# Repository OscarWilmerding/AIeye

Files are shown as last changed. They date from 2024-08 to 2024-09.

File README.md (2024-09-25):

# AIeye

If you are interested in buying a kit for this fill out this form, if there are enough people I will make and sell kits:
https://forms.gle/SYHFhyDxsT9Xxbqz5
Main repository for the AIeye camera project.

## Supplies

### Parts List
| Name | Quantity | Total Price | Link | Notes |
|---|---|---|---|---|
| Raspberry Pi Zero 2W | 1 | $26 | [Amazon](https://amzn.to/3Aza8KZ) | |
| Display | 1 | $18 | [Amazon](https://amzn.to/3WQWfPW) | |
| Camera | 1 | $9.50 | [Amazon](https://amzn.to/4cCxRY8) | |
| Camera Ribbon Cable | 1 | $9 | [Amazon](https://amzn.to/3AAfSnO) | You need this because the Pi Zero has a different ribbon cable than the regular Pi |
| Custom PCB | 1 | $9 | Recommend [PCBWay](https://www.pcbway.com/) or [JLCPCB](https://jlcpcb.com/) | You will need to upload the PCB zip file to the respective website |
| PCB Part - Button Power Switch | 1 | $1.85 | [Digi-Key](https://www.digikey.com/en/products/detail/cw-industries/GPTS203211B/3190590) | |
| PCB Part - Rotary Encoder | 1 | $2.60 | [Digi-Key](https://www.digikey.com/en/products/detail/cui-devices/RIC11-22S16D5M-TH/21705934) | |
| PCB Part - Alternate Encoder | * | * | [Digi-Key](https://www.digikey.com/en/products/detail/cui-devices/RIC11-22S15D7-TH/21705936) | Footprint should be the same for the PCB, but you may need to modify the 3D file for the knob so it fits on the shaft |
| PCB Part - Alternate Encoder | * | * | [Digi-Key](https://www.digikey.com/en/products/detail/cui-devices/RIC11-22S13D5S-TH/21705929) | Footprint should be the same for the PCB, but you may need to modify the 3D file for the knob so it fits on the shaft |
| PCB Part - Voltage Converter | 1 | $3.95 | [Digi-Key](https://www.digikey.com/en/products/detail/adafruit-industries-llc/4654/12697636) | |
| PCB Part - Momentary Button | 2 | $0.10 | [Digi-Key](https://www.digikey.com/en/products/detail/c-k/PTS636-SK43-LFS/10071716) | |
| PCB Part - Female Battery Port | 1 | $0.12 | [Digi-Key](https://www.digikey.com/en/products/detail/jst-sales-america-inc/S2B-PH-K-S/926626) | |
| Battery | 1 | $10.95 | [Digi-Key](https://www.digikey.com/en/products/detail/sparkfun-electronics/PRT-18286/14302550) | |
| Battery Charger | 1 | $10.96 | [Amazon](https://amzn.to/3yW2CcH) | |

**Total:** ~$102.03  
*Probably will cost 10-20% more with shipping included.*

---

### Other Needed Supplies

| Name | Quantity | Link | Notes |
|---|---|---|---|
| 3D Printed Parts | | | |
| M3 Screws | 2 short (5-10mm), 2 long (15-25mm) | | 3D file could be modified for similarly sized screws to fit |
| Super Glue or Hot Glue | | | |
| Sandpaper | | | If you want to improve the surface quality of the prints |
| Spray Paint | | | If you are not using colored filament and want to change the surface finish |
| Soldering Iron | | [Amazon](https://amzn.to/3Z03ozY) | For making the circuit board |
| Wire | | | I used 24 ga, but similarly sized copper wire should work the same (solid core wire may be trickier to solder) |
| MicroSD Card | | [Amazon](https://amzn.to/4763LuP) | |
| SD Card Reader | | | Some way to read the SD card |

---

### Recommended if You Need to Debug

- **Mini HDMI to HDMI Adapter**
- **Micro USB OTG Adapter**
- **Mouse**
- **Keyboard**

## 3D Printing

- **Layer Height**: 0.2mm
- **Infill**: 10%
- **Printer**: Printed on an Ender 3 S1 (any FDM printer will suffice).
- **Material**: PLA+
- **Supports**: The only parts that require supports are the overhangs above the screen and button panel. I'm using organic supports and forcing the slicer to only generate supports in these areas using the painted support enforcer tool.
- **Orientation**: Some parts are designed to be printed in a specific orientation. Refer to the image below for correct orientations:
  
  

## Circuit Board

- **PCB Fabrication**: You'll need to get a custom PCB fabricated; I recommend using PCBway.
- **Soldering Components**: Start by soldering the through-hole components to the board. These are highlighted below. Note how the voltage regulator is mounted slightly off the board. The orientation of the buttons does not matter. Just make sure all the components are soldered to the front side of the board (the side with the text on it).
  
  
  
  
- **Battery Cord**: Solder wires to the female battery port, and use plenty of shrink wrap to avoid short circuits. When soldering it onto the board, ensure that when the battery is plugged in, the ground goes to the ground pad (the square one). These connectors are easy to mix up and wire backward. It won't damage the device, but if you wire the positive and gnd backwards it will not turn on. The side of the board you solder it to doesn't matter as long as ground goes to ground (square pad). Below is a close-up of the battery connection:
  
  
  

- **5V Connection**: Solder the 5V connection wire to the board. This is soldered on the underside of the board to avoid short circuits if the solder joint faces directly towards the board.
- **Camera Ribbon Cable**: Connect the camera ribbon cable carefully. The port on the Pi is delicate, and if you don't push the plastic piece directly in or out, it can snap off easily.
- **Header Pins**: Solder the header pins onto the Pi and then solder the board onto the Pi. In the image, you’ll see two damaged, dusty pins. These were unnecessary and have been removed from the PCB fab file. The blackboard should connect as far to the right as possible with all of the Pi's header pins still going through the board.
- **5V Connection to Pi**: Solder the 5V connection cord to the back of the Pi. It needs to connect to the 5V pin on the back, not the front, to avoid interference with the screen.
  
  
  
- **Screen Connection**: Press the screen onto the header pins. It should be on the far left of the pins.
  
  

- **Testing**: Before placing it in the enclosure, test to ensure everything is working correctly.

## Software/Code

- **Overview**:
  - The project runs on PIOS, which is a slow but functional operating system. It takes a long time to boot up.
  - Once booted, it runs a Python script that displays the camera's GUI using a library called Pygame.

- **Flashing the SD Card**:
  - Use [win32diskimager](https://sourceforge.net/projects/win32diskimager/) to flash the SD card with the camera's code.
  - Download win32diskimager.
  - Download the `.img` file from my repository. 
    - https://drive.google.com/drive/folders/1noxVPlFzV9c3eGpXCnVfaX7x1-svAIYr?usp=sharing
  - Within win32diskimager, select your SD card, then select your downloaded image and click write. This process can take 10-30 minutes.
  
- **Configuring the SD Card**:
  - Once the image is flashed, remove the SD card and reinsert it into your computer.
  - Open the drive from your computor, and you should see a few folders. Many of the files are folders that the Raspberry Pi will rely on when it boots.
  - There should be a folder called `wifi credentials`, edit the text file and replace the credentials with the wifi credentials you wish the camera to use.
    - You can add your home Wi-Fi later, but not at this point.
    - You can make these credentials your mobile hotspot so you can take the camera outside your house. If you don’t want it to leave your house, just add your home Wi-Fi.
    - You can replace these credentials with a second or third Wi-Fi network once you've booted up the camera and loaded them into memory, which I'll cover later.
    - Be warned mobile hotspots can be annoying to connect to from the Pi, in my experience my Iphone hotspot was far less reliable than my home wifi.
  - Notice the folder called the photos, you dont need to do anything with it now but this is where the photos are going to be saved to so if you want to take the photos off the camera then that's where you get them.
    
- **API Keys**:
  - In the folder labeled `API keys`, you'll need to enter two API keys: one for Astica and one for OpenAI. You only need to input the keys once; the program will pull from that file every time it runs.
    - To get the Astica API key, go to [Astica AI](https://astica.ai/).
    - You'll need to add funds to Vision Compute. I recommend adding $10. Each image costs roughly $0.03 for Astica and OpenAI, so about $0.06 per image.
    - For the OpenAI key, go to [OpenAI Platform](https://platform.openai.com/settings/profile?tab=api-keys).
    - You'll need to create a user API key, which is now considered legacy. I recommend adding $10 to it as well.
    
- **Final Steps**:
  - Once you’ve added the API keys to the text file, you should be all set! Plug in the battery and power it on with the large button.
  - Once fully booted, press the middle button to open the settings menu, then press the knob to load the Wi-Fi settings. If you find that the camera is taking photos that are 90° or 180° off, go to the second menu in the settings and click rotate 90 degrees.
  - If you want to get the photos off of the pi then remove the sd card, plug it in your computor, and all the photos should be in the folder called photos.

- **Controls:**
  - When the "a normal photo" screen is being displayed this is the home screen, press the knob in to take a photo. Rotate the knob to change what the descriptor is for the photo you are taking.
  - Leftmost button is the power switch, you will need to press it more than the other 2 buttons to get it to click.
  - Middle button is settings
    - Once in the settings twist the know to navigate to which setting you want to do. When you press the knob in it will load the setting. 
  - Right button is playback. Press it and you will be able to see all the photos you have already taken. Press it again to go back to the screen with the descriptor sentence where you can take the photo.
  

## Debugging

- **Troubleshooting**:
  - If you ever need to login (which you shouldent), then the username is oewil and the password is 23309th. no I dont use that username or password anywhere else.
  - If something isn’t working, you'll need to connect to the Pi directly. You can do this by opening the bottom and plugging a mini HDMI cable and keyboard into the Pi. Alternatively, you can connect to the Pi via VNC Viewer. Note that you will not be able to connect to the Pi via VNC Viewer if it isn’t connected to the internet.
  - once you connect to the pi via vnc viewer you will need to press the escape key to ente the desktop
  - I have also included an image for the camera where the drivers to make it fit to the screen are not included. This may be easier to modify code as the screen will not be small on the VNC viewer.
  - You should also use this if you want to upgrade the screen.
  - If you want to run the script without booting on the entire camera, you are going to need to go to the terminal and run the command: sudo -E python3 cam_v3.py

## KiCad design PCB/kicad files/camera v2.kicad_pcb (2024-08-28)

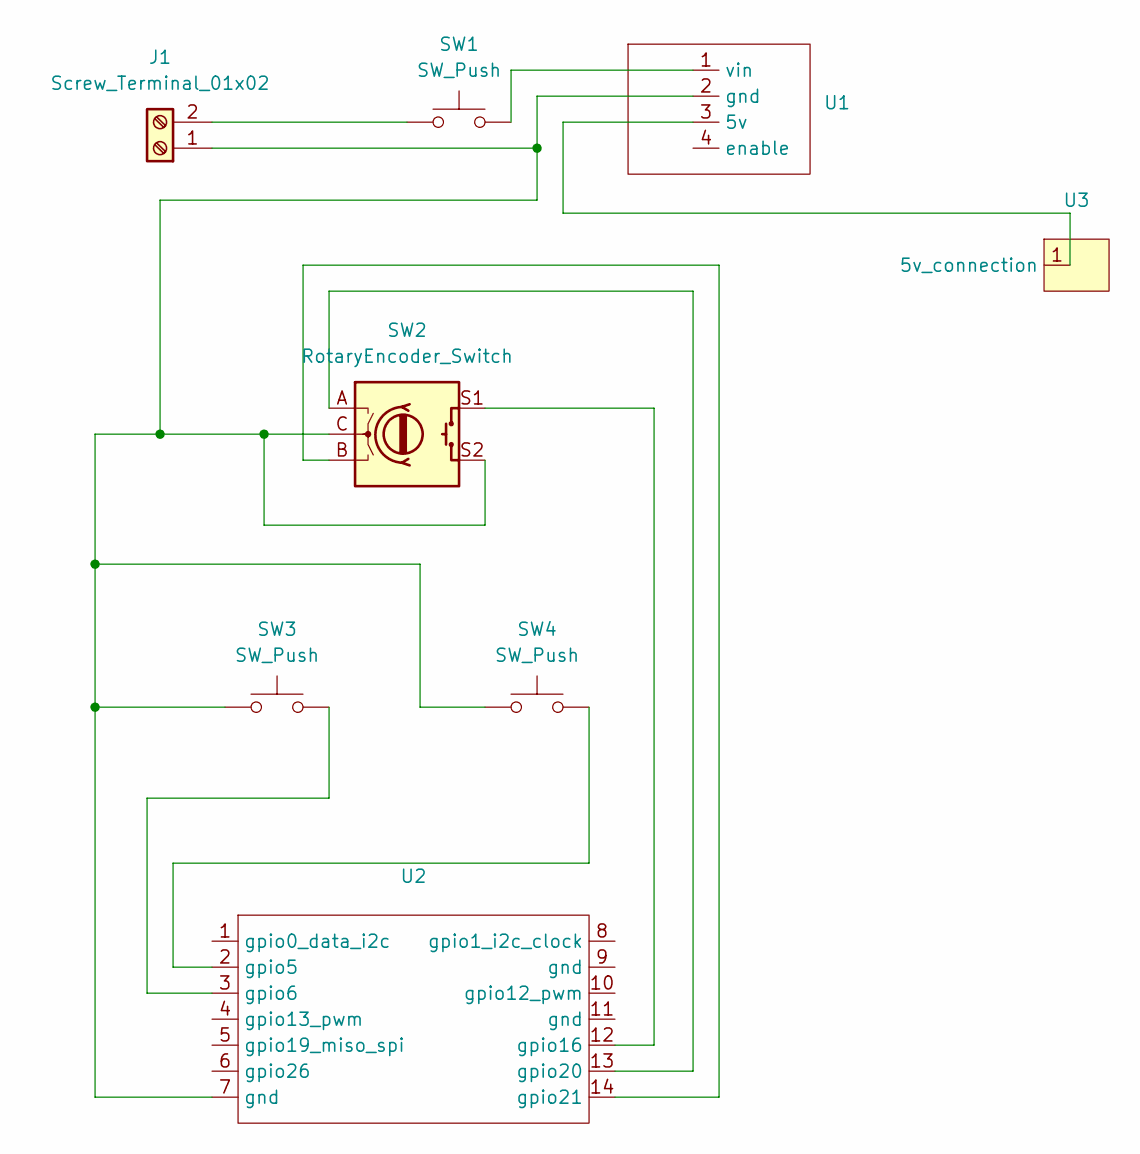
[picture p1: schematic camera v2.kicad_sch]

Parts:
J1: Screw_Terminal_01x02; connection for jst wires
SW1: SW_Push; button switch
SW2: RotaryEncoder_Switch; encoder
SW3, SW4: SW_Push; button
U1: mini boost
U2: pi segment
U3: 5v connection

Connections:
unnamed: J1.1, SW2.C, SW2.S2, SW3.1, SW4.1, U1.2 (gnd), U2.7 (gnd)
unnamed: J1.2, SW1.1
unnamed: U1.3 (5v), U3.1 (5v_connection)
unnamed: SW1.2, U1.1 (vin)
unnamed: SW4.2, U2.2 (gpio5)
unnamed: SW3.2, U2.3 (gpio6)
unnamed: SW2.S1, U2.12 (gpio16)
unnamed: SW2.A, U2.13 (gpio20)
unnamed: SW2.B, U2.14 (gpio21)

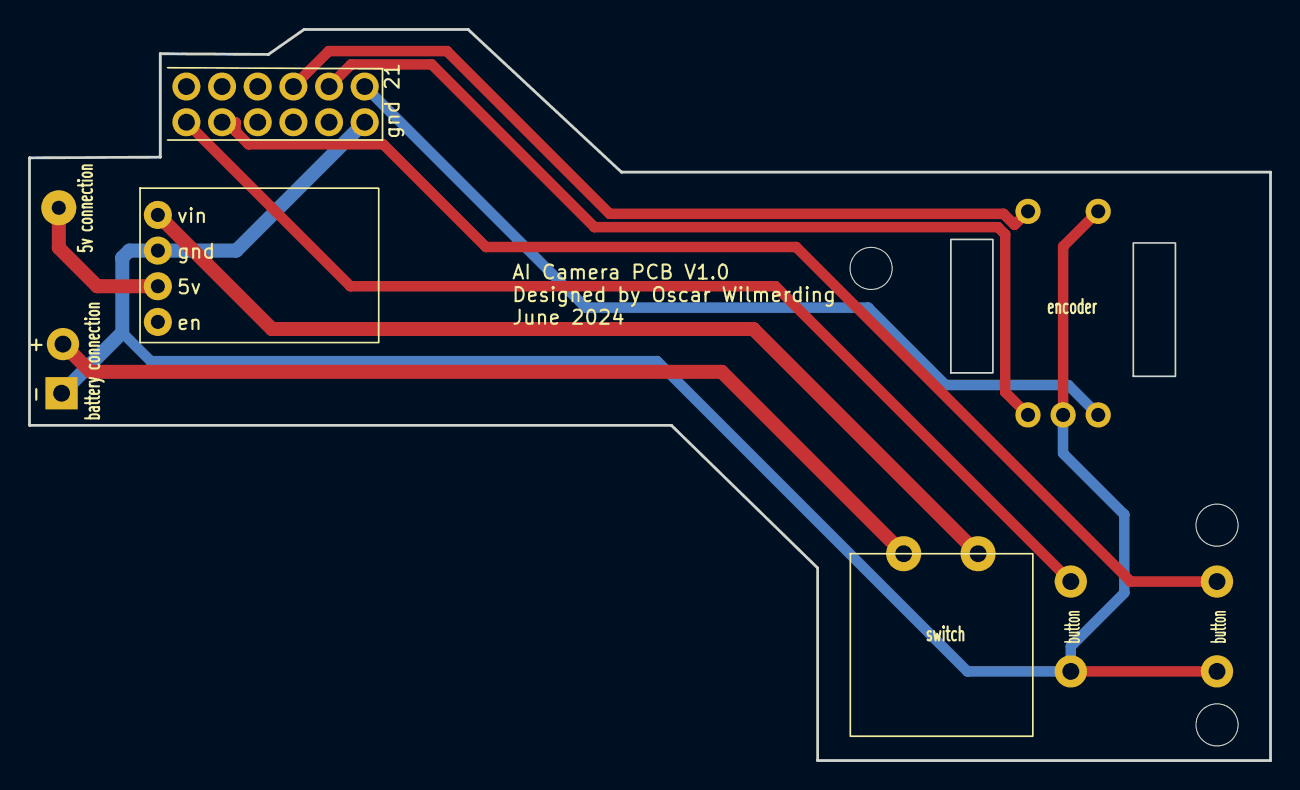
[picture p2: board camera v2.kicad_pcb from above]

Board: 2 copper layers, 88.4 x 52.1 mm, 8 parts (0 on the bottom side), 9 nets.

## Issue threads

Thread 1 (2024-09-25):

Add Python Code to Repo?

vektorious, 2024-09-25:
Hey @OscarWilmerding,

Great project and beautiful design! I'm working on a similar project, but I'm using a Stable Diffusion image to image model to generate new images from the images I'm taking based on an additional prompt.

I would love to build your camera design but would like to introduce some changes to the code to use an image-to-image model. Would you mind sharing the code here in your repository? As far as I can see, there is only a text file in the python folder. Would you also mind sharing your setup routine instead of the OS image? It does not need to be perfect.

Thanks again for your great work!

OscarWilmerding, 2024-09-25:
Hi Alexander,

Thanks for taking interest in the project! The python code was added to the
repo. I can tell you a rough idea of what you need to do to set it up but
know that the reason I did it as an img file was because the setup was a
bit of a pain in the ass.

The pi is running pi OS, I tried to get it to run pi OS lite but gave up as
I found it to be a little to inconvenient. the reason I tried pi os lite
was because the boot time for the camera is REALLY bad, like a minute to
boot up.

you are going to need to change the permissions in the sudo raspi-config
settings to allow permissions for legacy camera support. I also reccomend
enabling VNC which will allow you to connect to and control the pi from
your computor.

I reccomend downloading the drivers for the screen LAST, once you install
the drivers for the screen the desktop will be super small and hard to work
with.

Once os is installed you are going to want to try to get the script to run.
the script has a lot of dependencies so you will have to download all the
libraries. additionally to run the script you cant just run it normally
(like you would in the code editor), you need to run it with more
permisions in the terminal. use the command sudo -E python3 cam_v3. cam_v3
is the script in question being run.

I think thats most of the setup, another thing I did was got it so the
script automatically just ran after the pi booted up, which I totally
forgot how I did it. I used hat gpt for a lot of the advice and it took a
while to get this step to work because the Pi doesnt love running a file
with special permissions on boot.

I know thats a lot and theres a ton of typos, but I wish you luck! please
reach out if you think I can help.

-Oscar

On Wed, Sep 25, 2024 at 3:32 AM Alexander Kutschera <
***@***.***> wrote:

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

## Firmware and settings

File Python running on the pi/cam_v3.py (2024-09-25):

import sys
import pygame
import subprocess
import time
import requests
import json
import base64
import os
from openai import OpenAI
from io import BytesIO
from PIL import Image, ImageDraw, ImageFont
import textwrap
from gpiozero import RotaryEncoder, Button
from signal import pause
import threading

# Global variables for API keys and settings
ASTICA_API_KEY = ''
OPENAI_API_KEY = ''
ASTICA_API_TIMEOUT = 25
ASTICA_API_ENDPOINT = 'https://vision.astica.ai/describe'
ASTICA_API_MODEL_VERSION = '2.1_full'
ASTICA_API_VISION_PARAMS = 'gpt'

# Define global variables for the indices and lists
var1_index = 0
var1_list = ['normal', 'melancholy', 'awe inspiring', 'desolate', 'tranquil', 'evil', 'vengeful', 'nostalgic', 'mysterious', 'hyper-realistic', 'chaotic', 'weird', 'unhinged','robotic', 'overgrown', 'brutalist', 'devious']

#for settings menu
settings_options = ['Load WiFi Credentials, Must Reboot After', 'Update Photo Rotation']  #option 3 and option 4 are settings options names that have a template for a command to be executed in the execute_settings_option function if you want to add them here
settings_index = 0

encoder_var1 = RotaryEncoder(20,21)
button_var1 = Button(16)
button_var2 = Button(5, pull_up=True)  #  button for 'settings'
button_var3 = Button(6, pull_up=True)  #  button for 'playback

bg_color = pygame.Color("#1E2438")
text_color = pygame.Color("#F1F2ED")
font_path = "/home/oewil/Documents/Futura Std Heavy Oblique.otf"
font_size = 24

image_values = 0
knob_value = 0

# Initialize Pygame and set up the display
def init_pygame():
    pygame.init()
    screen = pygame.display.set_mode((0, 0), pygame.FULLSCREEN)
    global custom_font
    custom_font = pygame.font.Font(font_path, font_size)
    pygame.mouse.set_visible(False)
    return screen

screen = init_pygame()

directory = "/boot/photos"

def create_text_image(paragraph, theme_word, font_path, font_size=52, image_width=800, image_height=600, 
                      text_color="#FFFFFF", bg_color="#000000", margin=50, save_path="output_image.png"):
    """Creates an image with a theme label above a centered paragraph of text.

    Args:
        paragraph (str): The paragraph of text to display.
        theme_word (str): The single word theme to display above the paragraph.
        font_path (str): Path to the font file to use.
        font_size (int, optional): Font size for the text. Defaults to 24.
        image_width (int, optional): Width of the image in pixels. Defaults to 800.
        image_height (int, optional): Height of the image in pixels. Defaults to 600.
        text_color (str, optional): Hex color code for the text color. Defaults to "#FFFFFF".
        bg_color (str, optional): Hex color code for the background color. Defaults to "#000000".
        margin (int, optional): Margin between the text and the edges of the image. Defaults to 50.
        save_path (str, optional): Filepath to save the image. Defaults to "output_image.png".
    """
    # Create a blank image with the specified background color
    image = Image.new('RGB', (image_width, image_height), color=bg_color)
    draw = ImageDraw.Draw(image)

    # Load the specified font
    font = ImageFont.truetype(font_path, 48)
    # Prepare the theme text
    theme_text = f"A {theme_word} image"
    theme_width, theme_height = draw.textsize(theme_text, font=font)

    # Split the paragraph into lines of 7 words each
    words = paragraph.split()
    lines = [' '.join(words[i:i + 7]) for i in range(0, len(words), 7)]

    # Calculate the height of the paragraph text
    line_height = font.getsize('Ag')[1]
    line_spacing = 18  # Spacing between lines
    num_lines = len(lines)
    total_paragraph_height = num_lines * line_height + (num_lines - 1) * line_spacing

    # Calculate the total height of the combined text block (theme text + paragraph)
    total_text_height = theme_height + total_paragraph_height

    # Calculate the starting y position to vertically center the combined text block
    start_y = (image_height - total_text_height) // 2

    # Draw the theme text at the calculated position
    theme_x = (image_width - theme_width) // 2
    draw.text((theme_x, start_y), theme_text, font=font, fill=text_color)

    # Draw each line of the paragraph text on the image, centered horizontally
    text_y_position = start_y + theme_height

    for line in lines:
        line_width, _ = draw.textsize(line, font=font)
        text_x_position = (image_width - line_width) // 2
        draw.text((text_x_position, text_y_position), line, font=font, fill=text_color)
        text_y_position += line_height + line_spacing

    # Save the image to the specified path
    image.save(save_path)
    print(f"Image saved to {save_path}")

def load_rotation_value():
    """Loads the rotation value from the text file."""
    rotation_file = '/home/oewil/rotation_value'
    try:
        with open(rotation_file, 'r') as file:
            rotation_value = int(file.read().strip())
            return rotation_value
    except FileNotFoundError:
        return 0  # Default to 0 if the file doesn't exist
    except ValueError:
        return 0  # Default to 0 if there's an error in reading the file

def get_file_by_recency(index):
    # Ensure index is non-negative
    index = max(0, index)

    # Get all files in the directory, sorted by modification time (most recent first)
    try:
        files = [os.path.join(directory, f) for f in os.listdir(directory)]
        files = [f for f in files if os.path.isfile(f)]
        files.sort(key=os.path.getmtime, reverse=True)
    except Exception as e:
        return f"Error accessing directory or sorting files: {str(e)}"

    # Check if the index is within the bounds of available files
    if index >= len(files):
        # If index is out of bounds, return the oldest file
        index = len(files) - 1 if files else 0  # Adjust index to the oldest file's index

    # Return the path of the file corresponding to the adjusted index
    return files[index] if files else "No files found in the directory"

def display_image(image_values):
    image_path = get_file_by_recency(image_values)

    # Load the image from the path and maintain aspect ratio
    def load_and_scale_image(path, screen_size):
        # Load the image
        image = pygame.image.load(path)
        # Determine scaling factor to maintain aspect ratio
        img_width, img_height = image.get_size()
        scale = min(screen_size[0] / img_width, screen_size[1] / img_height)
        # Apply scaling
        new_width = int(img_width * scale)
        new_height = int(img_height * scale)
        return pygame.transform.scale(image, (new_width, new_height))

    # Center and draw the image on the screen
    def draw_image_centered(screen, image):
        img_width, img_height = image.get_size()
        screen_size = screen.get_size()
        x = (screen_size[0] - img_width) // 2
        y = (screen_size[1] - img_height) // 2
        screen.blit(image, (x, y))

    # Clear the screen with the specified background color
    screen.fill((25, 25, 25))

    # Load, scale, and draw the image
    image = load_and_scale_image(image_path, screen.get_size())
    draw_image_centered(screen, image)

    # Update the display
    pygame.display.flip()

def display_filler_text(screen, custom_font, sentence, text_color, bg_color):
    screen.fill(bg_color)
    screen_width, screen_height = screen.get_size()
    text_surface = custom_font.render(sentence, True, text_color)
    text_rect = text_surface.get_rect(center=(int(screen_width / 2), int(screen_height / 2)))
    screen.blit(text_surface, text_rect)
    pygame.display.flip()

# Load and render text
def render_text(screen, custom_font, sentence, text_color, bg_color):
    screen.fill(bg_color)
    screen_width, screen_height = screen.get_size()
    text_surface = custom_font.render(sentence, True, text_color)
    text_rect = text_surface.get_rect(center=(int(screen_width / 2), int(screen_height / 2)))
    screen.blit(text_surface, text_rect)
    pygame.display.flip()

def update_rotation_value():
    """Updates the rotation value by adding 90. Resets to 0 if the value is 360."""
    rotation_file = '/home/oewil/rotation_value'
    rotation_value = load_rotation_value()
    
    # Add 90 degrees to the current rotation value
    rotation_value += 90
    
    # Reset to 0 if the value is 360
    if rotation_value >= 360:
        rotation_value = 0
    
    # Save the updated rotation value back to the file
    with open(rotation_file, 'w') as file:
        file.write(str(rotation_value))
    
    print(f"Rotation value updated to {rotation_value}°")
    return rotation_value

def take_photo_and_save():
    """Takes a photo and saves it with a Unix timestamp-based filename using rotation value from the text file."""
    photo_timestamp = int(time.time())
    photo_filename = f"img_{photo_timestamp}.jpg"
    photo_directory = '/boot/photos'
    photo_path = os.path.join(photo_directory, photo_filename)

    rotation_value = load_rotation_value()

    try:
        subprocess.run(['raspistill', '-o', photo_path, '-rot', str(rotation_value)], check=True)
        print(f"Photo saved to {photo_path} with rotation {rotation_value}°")
        return photo_path, photo_timestamp  # Return both path and timestamp
    except subprocess.CalledProcessError as e:
        print(f"Failed to take photo: {e}")
        return None, None  # Return None for both values on failure

def get_image_base64_encoding(image_path):
    """Encodes an image at `image_path` to a base64 string."""
    with open(image_path, 'rb') as file:
        image_data = file.read()
    image_extension = os.path.splitext(image_path)[1]
    return f"data:image/{image_extension[1:]};base64,{base64.b64encode(image_data).decode('utf-8')}"

def asticaAPI(payload):
    """Sends a request to the asticaVision API and returns the response."""
    headers = {'Content-Type': 'application/json'}
    response = requests.post(ASTICA_API_ENDPOINT, data=json.dumps(payload), timeout=ASTICA_API_TIMEOUT, headers=headers)
    if response.status_code == 200:
        return response.json()
    else:
        print("Failed to connect to the API.")
        return None

def save_image_from_url(url, timestamp):
    """Downloads an image from a URL and saves it with the Unix timestamp."""
    try:
        response = requests.get(url)
        response.raise_for_status()

        image = Image.open(BytesIO(response.content))
        image_name = f"img_{timestamp}_GENERATED.jpg"  # Use the timestamp here

        save_path = os.path.join("/boot/photos", image_name)
        image.save(save_path)

        print(f"Image saved successfully to {save_path}")
    except requests.exceptions.RequestException as e:
        print(f"Failed to download the image: {e}")
    except IOError as e:
        print(f"Failed to save the image: {e}")

def display_image_from_url(url):
    """Fetches and displays an image from `url`."""
    response = requests.get(url)
    if response.status_code == 200:
        Image.open(BytesIO(response.content)).show()
    else:
        print("Failed to fetch the image.")

def cam_sequence(mood):
    """Main function orchestrating the process."""
    print(f"Python version: {sys.version}")
    print(f"sys.path: {sys.path}")

    image_path, image_timestamp = take_photo_and_save()  # Capture both values
    if not image_path:
        return

    display_filler_text(screen, custom_font, "Analyzing photo and generating description", text_color, bg_color)

    asticaAPI_input = get_image_base64_encoding(image_path)
    asticaAPI_payload = {
        'tkn': ASTICA_API_KEY,
        'modelVersion': ASTICA_API_MODEL_VERSION,
        'visionParams': ASTICA_API_VISION_PARAMS,
        'input': asticaAPI_input,
    }

    api_result = asticaAPI(asticaAPI_payload)
    if not api_result:
        return

    print('\nastica API Output:')
    print(json.dumps(api_result, indent=4))

    display_filler_text(screen, custom_font, "Generating a new image", text_color, bg_color)

    if api_result.get('status') == 'success':
        raw_description = api_result.get("caption_GPTS", "")
        
        create_text_image(paragraph = raw_description, theme_word = mood, font_path=font_path, font_size=34, image_width=1200, image_height=1200, 
                      text_color = (241,242,237), bg_color = (30,36,56), margin=50, save_path=f"/boot/photos/img_{str(int(time.time()))}.jpg")
        final_description = f"the most important part of this image is that the mood is {mood}, the image should look like this: {raw_description}. REMEMBER that the general mood should be {mood}. Please make sure the mood is {mood} that is the most important part of this image."
        print("final description = " + final_description)
        client = OpenAI(api_key=OPENAI_API_KEY)
        response = client.images.generate(
            model="dall-e-3",
            prompt=final_description,
            size="1024x1024",
            quality="standard",
            n=1,
        )
        image_url = response.data[0].url
        print(image_url)
        save_image_from_url(image_url, image_timestamp)  # Pass the timestamp here

def display_sentence():
    global var1_index
    sentence = f"A {var1_list[var1_index]} photo."

    screen.fill(bg_color)
    screen_width, screen_height = screen.get_size()
    text_surface = custom_font.render(sentence, True, text_color)
    text_rect = text_surface.get_rect(center=(int(screen_width / 2), int(screen_height / 2)))
    screen.blit(text_surface, text_rect)
    pygame.display.flip()

def update_values(change):
    global var1_index, image_values, settings_index
    if current_display == 'text':
        var1_index = (var1_index + change) % len(var1_list)
        print(f'Mood index changed to {var1_index}')
        display_sentence()
    elif current_display == 'image':
        print(f'change detected is {change}')
        image_values = max(0, image_values - change)
        print(f'value changed for the image menu, now {image_values}')
        display_image(image_values)
    elif current_display == 'settings':
        settings_index = (settings_index + change) % len(settings_options)
        print(f'Settings option changed to: {settings_options[settings_index]}')
        display_settings_option()
    elif current_display == 'playback':
        image_values = max(0, image_values - change)
        print(f'value changed for the playback menu, now {image_values}')
        display_image(image_values)

def display_settings_option():
    option = settings_options[settings_index]
    display_filler_text(screen, custom_font, f"Settings: {option}", text_color, bg_color)

def execute_settings_option():
    option = settings_options[settings_index]
    message = 'you should not see this'
    if option == 'Load WiFi Credentials, Must Reboot After':
        success = load_wifi_credentials()
        message = "WiFi Credentials Loaded Successfully" if success else "Failed to Load WiFi Credentials"
    elif option == 'Update Photo Rotation':
        update_rotation_value()
        print("Executing screen rotation")
        message = "Photos taken are now rotated 90 degrees clockwise"
    elif option == 'Option 3':
        print("Executing Option 3")
        message = "Option 3 Executed"
    elif option == 'Option 4':
        print("Executing Option 4")
        message = "Option 4 Executed"
    
    display_filler_text(screen, custom_font, message, text_color, bg_color)
    time.sleep(2)  # Display the message for 2 seconds
        
    display_settings_option()  # Return to settings display

def on_button_press(button):
    global current_display, screen, image_values, var1_index
    print(f'Button {button.pin.number} has been pressed')
    
    if button.pin.number == 16:  # Original button
        print("Original button pressed")
        if current_display == 'text':
            display_filler_text(screen, custom_font, "Taking Photo", text_color, bg_color)
            cam_sequence(var1_list[var1_index])
            display_image(0)
            image_values = 0
            current_display = 'image'
        elif current_display == 'settings':
            execute_settings_option()
        else:
            display_sentence()
            current_display = 'text'
            image_values = 0
    elif button.pin.number == 5:  # New 'settings' button
        print("Settings button pressed")
        if current_display != 'settings':
            current_display = 'settings'
            display_settings_option()
        else:
            current_display = 'text'
            display_sentence()
    elif button.pin.number == 6:  # New 'playback' button
        print("Playback button pressed")
        image_values = 0
        if current_display != 'image':
            current_display = 'image'
            display_image(image_values)
        else:
            current_display = 'text'
            display_sentence()
    
    print(f"Current display mode: {current_display}")

def load_wifi_credentials(file_path="/boot/WiFi Credentials/WiFi Credentials.txt"):
    # Check if the file exists
    if not os.path.exists(file_path):
        print(f"Error: Wi-Fi credentials file not found at {file_path}")
        return False

    try:
        # Read Wi-Fi credentials from the file
        with open(file_path, "r") as file:
            ssid = file.readline().strip()
            password = file.readline().strip()

        if not ssid or not password:
            print("Error: SSID and password are required")
            return False

        # Generate the hashed passphrase using wpa_passphrase
        result = subprocess.run(["wpa_passphrase", ssid, password], capture_output=True, text=True)

        # Extract the network block generated by wpa_passphrase
        network_config = ""
        inside_network_block = False
        for line in result.stdout.splitlines():
            if "network=" in line:
                inside_network_block = True
            if inside_network_block:
                network_config += line + "\n"
            if line == "}":
                inside_network_block = False

        # Path to wpa_supplicant.conf
        wpa_supplicant_path = "/etc/wpa_supplicant/wpa_supplicant.conf"

        # Check if we have write permissions
        if not os.access(wpa_supplicant_path, os.W_OK):
            print("Error: No write permission for wpa_supplicant.conf. Try running with sudo.")
            return False

        # Append the new network to wpa_supplicant.conf
        with open(wpa_supplicant_path, "a") as wpa_file:
            wpa_file.write(network_config)

        print(f"Wi-Fi credentials for '{ssid}' added successfully")

        # Reconfigure wpa_supplicant to apply changes
        subprocess.run(["wpa_cli", "-i", "wlan0", "reconfigure"], check=True)

        print("Wi-Fi configuration updated. The Pi will attempt to connect to the new network.")
        return True

    except Exception as e:
        print(f"Error loading Wi-Fi credentials: {str(e)}")
        return False

def load_ai_api_keys(file_path="/boot/API_keys/keys.txt"):
    # Initialize variables to store API keys
    astica_ai_key = None
    openai_key = None
    additional_keys = {}

    # Check if the file exists
    if not os.path.exists(file_path):
        print(f"Error: API key file not found at {file_path}")
        return None, None, {}

    try:
        with open(file_path, "r") as file:
            for line in file:
                line = line.strip()
                if line and '=' in line:
                    key, value = line.split('=', 1)
                    key = key.strip().lower()  # Convert to lowercase for case-insensitive comparison
                    value = value.strip()

                    if key == "astica ai key":
                        astica_ai_key = value
                    elif key == "openai key":
                        openai_key = value
                    else:
                        additional_keys[key] = value

        if not astica_ai_key or not openai_key:
            print("Error: Both Astica AI Key and OpenAI Key are required")
            return None, None, {}

        print("AI API keys loaded successfully")
        print(f"Astica AI Key: {astica_ai_key[:5]}...{astica_ai_key[-5:]}")
        print(f"OpenAI Key: {openai_key[:5]}...{openai_key[-5:]}")
        for key, value in additional_keys.items():
            print(f"{key}: {value[:5]}...{value[-5:]}")

        return astica_ai_key, openai_key

    except Exception as e:
        print(f"Error loading AI API keys: {str(e)}")
        return None, None, {}

def main():
    global custom_font, text_color, bg_color, current_display, values, ASTICA_API_KEY, OPENAI_API_KEY

    ASTICA_API_KEY, OPENAI_API_KEY = load_ai_api_keys()
    
    if ASTICA_API_KEY and OPENAI_API_KEY:
        print("AI API keys loaded successfully. Ready to use in main script.")
    else:
        print("Failed to load required AI API keys.")
        display_filler_text(screen, custom_font, "API KEYS NOT FOUND", text_color, bg_color)
        time.sleep(10)

    current_display = 'text'
    values = [0, 0]
    display_sentence()

    encoder_var1.when_rotated_clockwise = lambda: update_values(1)
    encoder_var1.when_rotated_counter_clockwise = lambda: update_values(-1)

    button_var1.when_pressed = lambda: on_button_press(button_var1)
    button_var2.when_pressed = lambda: on_button_press(button_var2)
    button_var3.when_pressed = lambda: on_button_press(button_var3)

    running = True
    while running:
        for event in pygame.event.get():
            if event.type == pygame.QUIT:
                running = False
            elif event.type == pygame.KEYDOWN and event.key == pygame.K_ESCAPE:
                running = False

    button_var1.close()
    button_var2.close()
    button_var3.close()
    encoder_var1.close()
    pygame.quit()
    sys.exit()
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
